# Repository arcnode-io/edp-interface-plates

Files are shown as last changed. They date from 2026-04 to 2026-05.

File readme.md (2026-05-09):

# EDP Interface Plates 🔩📐







> interface plates that mount to container end walls and organize all power, comms, and fluid connections

## Architecture Context

```plantuml
rectangle container_a
rectangle container_b
rectangle plate_a
rectangle plate_b
rectangle flexible_assembly

container_a -r- plate_a: receiver frame (welded)
container_b -l- plate_b: receiver frame (welded)
plate_a -r- flexible_assembly: liquid-tight conduit\nM12 connectors\ncooling QDs
flexible_assembly -r- plate_b
```

Containers are placed face-to-face. Plates mate as a pair via flexible assemblies — there is **no hard-dock interface**. Containers tolerate ±25mm horizontal and ±10mm vertical misalignment, absorbed by hose/cable service loops.

## Power Path

```
External BESS  →  BG  →  Grid Container  →  CG  →  Compute Container (415Y/240V AC)
```

Grid container always present. PCS lives in grid container when BESS is DC-coupled; when AC-coupled the BESS lands on grid switchgear directly.

## Plate Variants

Variant codes follow `[Container A][Container B]-[Coupling]-[String/Port Count]` where applicable.

| Variant | Used When | Carries | Plate Codes |
|---|---|---|---|
| **BG-AC** | External BESS lands AC at grid container (Tesla Megapack, Tesla Megablock, CATL EnerOne with integrated PCS) | AC feeder, grounding, data | `BG-AC` (conduit sized from BESS AC interconnect spec) |
| **BG-DC** | External BESS lands DC at grid container; PCS lives in grid container (CATL EnerOne, external PCS) | DC bus, grounding, data | `BG-DC` (single parametric variant, DC bus OD sized from aggregate string current per ADR-011) |
| **CG** | All deployments | AC feeder (415Y/240V) + data | `CG` (fixed, conduit sized from sizing engine Module F) |
| **CD** | All deployments (1:1 Compute:Drycooler) | Coolant supply/return + drycooler comms (VFD Modbus, fan tach, leak sensor) | `CD` (2" QD class, 200 LPM @ 5 K secondary loop ΔT) |

See the spec doc for full penetration schedules per variant.

## Material & Finish

| Parameter | Standard | Defense (`deployment_context == defense_forward \| sovereign_government`) |
|---|---|---|
| Outer dimensions | 640mm × 840mm | same |
| Thickness | 6mm | 10mm |
| Material | 6061-T6 aluminum (ASTM B209) | 5083-H116 marine grade (ASTM B209) |
| Finish | Type II anodize 15–25 μm (MIL-A-8625) | Type III hard anodize 40–60 μm |
| IP rating | IP55 | IP65 (verified per MIL-STD-810H Method 506) |
| Secondary seal | none | 10mm closed-cell EPDM backer |
| Fasteners | Zn-plated steel M10 (ASTM F593 G1) | 316 SS M10 (ASTM F593 G2) |

## Output Artifacts

For every plate variant required by a deployment, the implementation outputs:

1. **DXF file** — 2D fabrication drawing with plate outline, all hole/cutout locations dimensioned from plate center, gasket groove cross-section, mounting hole pattern with thread callouts, ARCNODE title block (part number, variant code, revision, material spec, finish spec).
2. **BOM line item** — structured JSON referencing the drawing:
   ```json
   {
     "part_number": "ARC-PLT-BG-DC-001",
     "description": "Interface Plate, BESS-to-Grid DC-Coupled, 4-String",
     "qty": 1,
     "material": "6061-T6 aluminum",
     "finish": "Type II anodize",
     "drawing_ref": "ARC-PLT-BG-DC-001.dxf",
     "type": "custom_fabrication"
   }
   ```
3. **Penetration schedule** — table of every hole/cutout: penetration ID, X/Y center coordinates from plate origin, diameter or W×H, fitting spec, OTS part number.

## Part Numbering

```
ARC - PLT - [VARIANT CODE] - [REVISION]

Examples:
  ARC-PLT-BG-AC-001       BESS-Grid, AC-coupled
  ARC-PLT-BG-DC-001       BESS-Grid, DC-coupled (single parametric variant)
  ARC-PLT-CG-001          Compute-Grid
  ARC-PLT-CD-001          Compute-Drycooler

Defense variants append `-D`:
  ARC-PLT-BG-DC-001-D
```

## Toolchain

The fabrication flow is CadQuery-based:

```
parametric model.py (CadQuery) → STEP → DXF + GD&T drawing → BOM line item + penetration schedule
```

```bash
uv sync
uv run poe build              # CadQuery → STEP per variant
uv run poe validate-model     # BRep validity + bbox vs spec
uv run poe generate-drawings  # DXF + GD&T PDF per variant
uv run poe sim                # IP rating verification fixtures
```

## Open Design Parameters

| # | Parameter | Impact |
|---|---|---|
| 1 | GPU vendor DLC loop architecture | CD plate QD port size and count |
| 2 | Dry cooler pipe connection size | CD plate flange size |
| 3 | 4,160V AC option | CG conduit sizing changes significantly at MV |
| 4 | BESS DC string voltage class (1500V vs 800V) | BG-DC isolation distance + bus rating |
| 5 | BESS AC interconnect voltage (480V vs MV) | BG-AC conduit + bushing class |

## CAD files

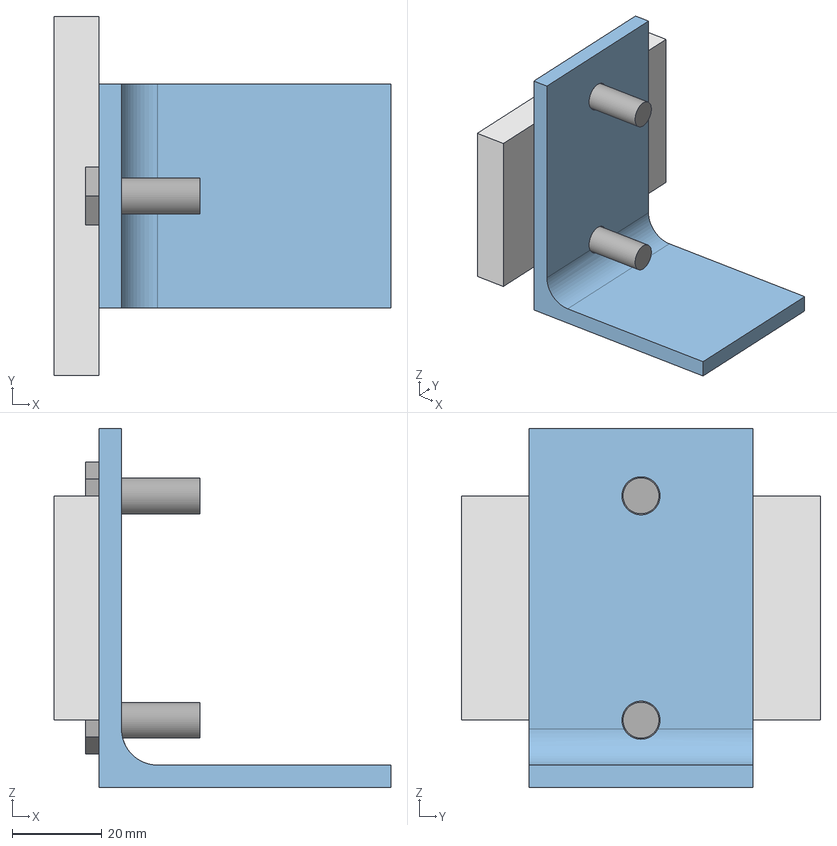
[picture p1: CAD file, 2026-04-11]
output/fab/l_bracket_assy.step
75.0 x 80.0 x 80.0 mm
bracket
wall_plate
bolt_1
bolt_2

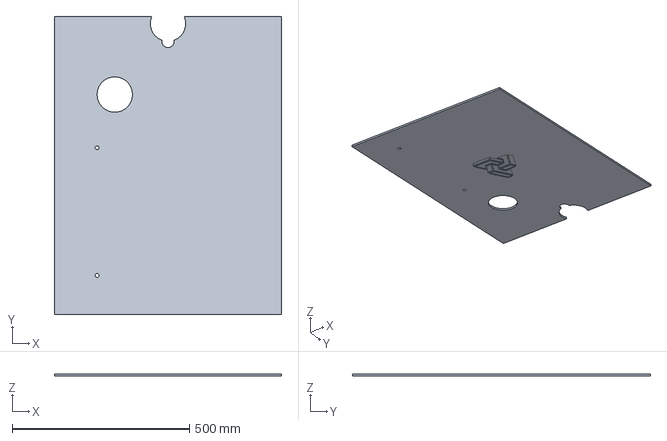
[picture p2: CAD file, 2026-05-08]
cad/BG-AC.step
640.0 x 840.0 x 6.00 mm

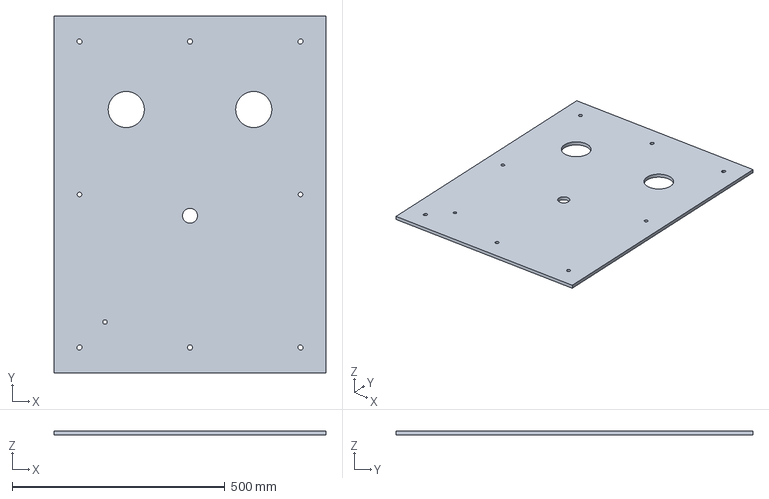
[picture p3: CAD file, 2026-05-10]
cad/specs/BG-DC/plate-defense.step
640.0 x 840.0 x 10.0 mm

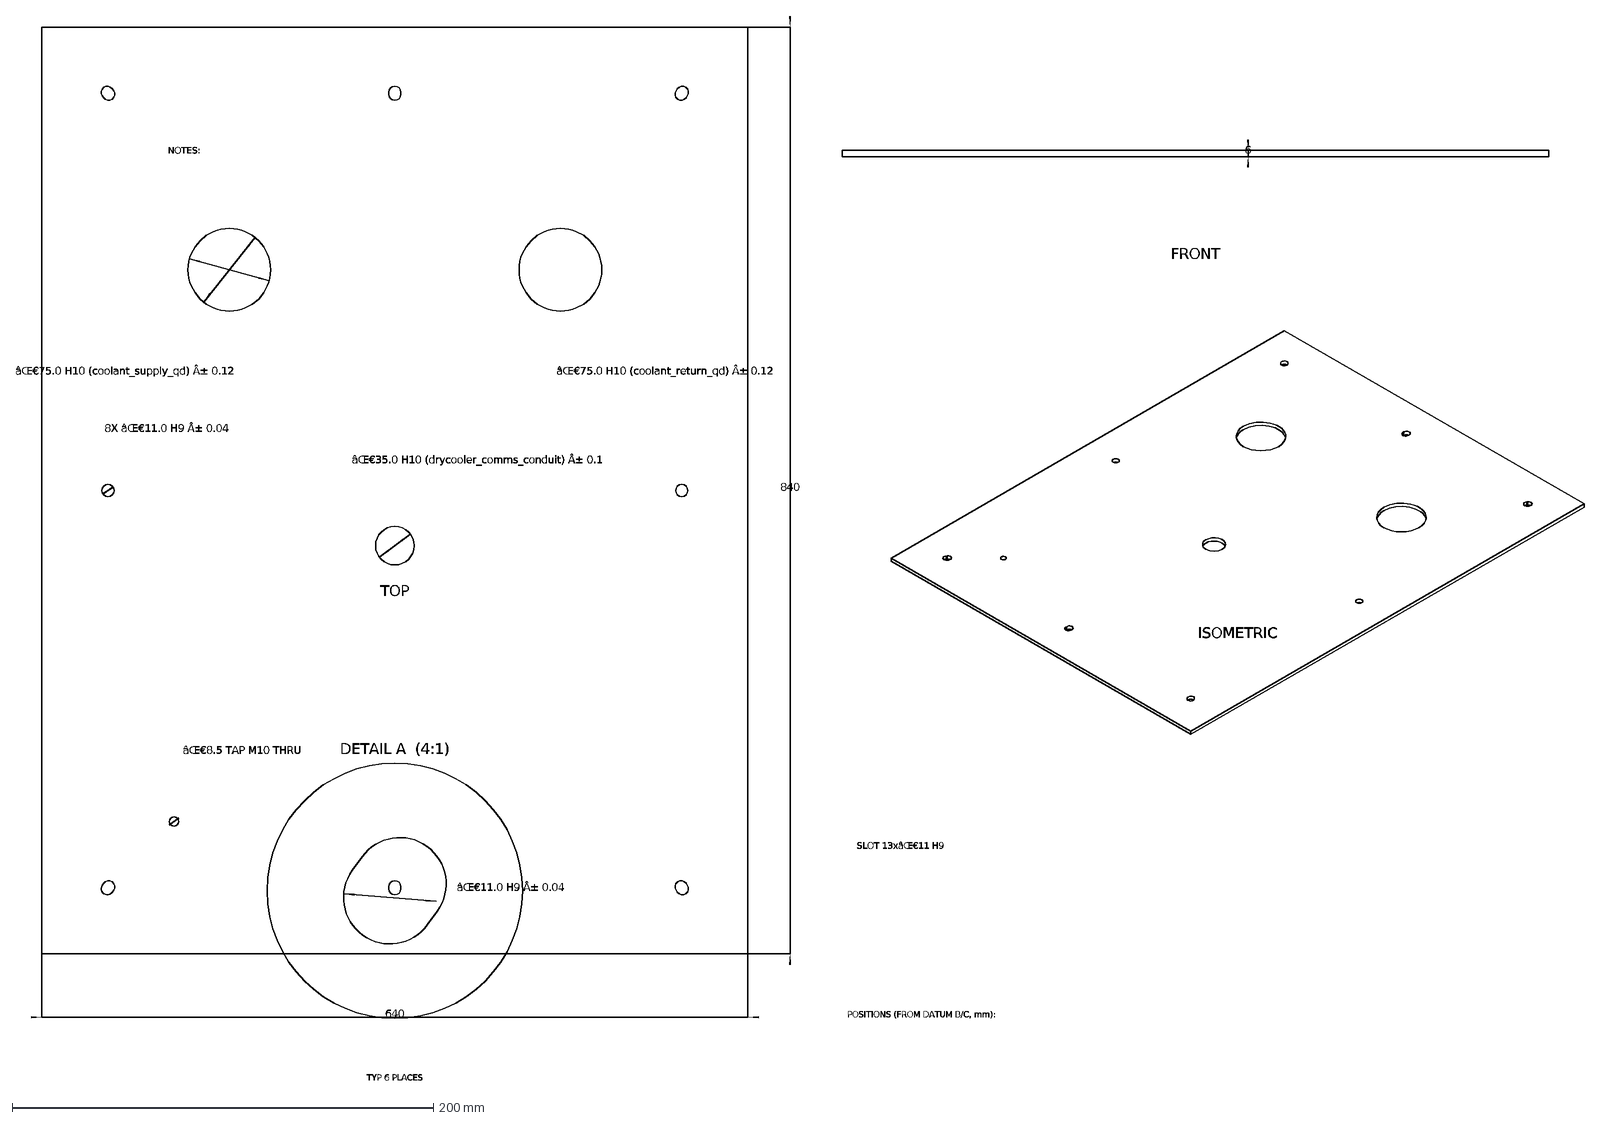
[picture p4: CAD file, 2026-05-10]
output/drawings/CD.dxf
640
840
âŒ€75.0 H10 (coolant_supply_qd) Â± 0.12
âŒ€75.0 H10 (coolant_return_qd) Â± 0.12
âŒ€35.0 H10 (drycooler_comms_conduit) Â± 0.1
âŒ€8.5 TAP M10 THRU
8X âŒ€11.0 H9 Â± 0.04
POSITIONS (FROM DATUM B/C, mm):
SLOT 13xâŒ€11 H9
6
âŒ€11.0 H9 Â± 0.04
TYP 6 PLACES
DETAIL A (4:1)
NOTES:
TOP
FRONT
ISOMETRIC

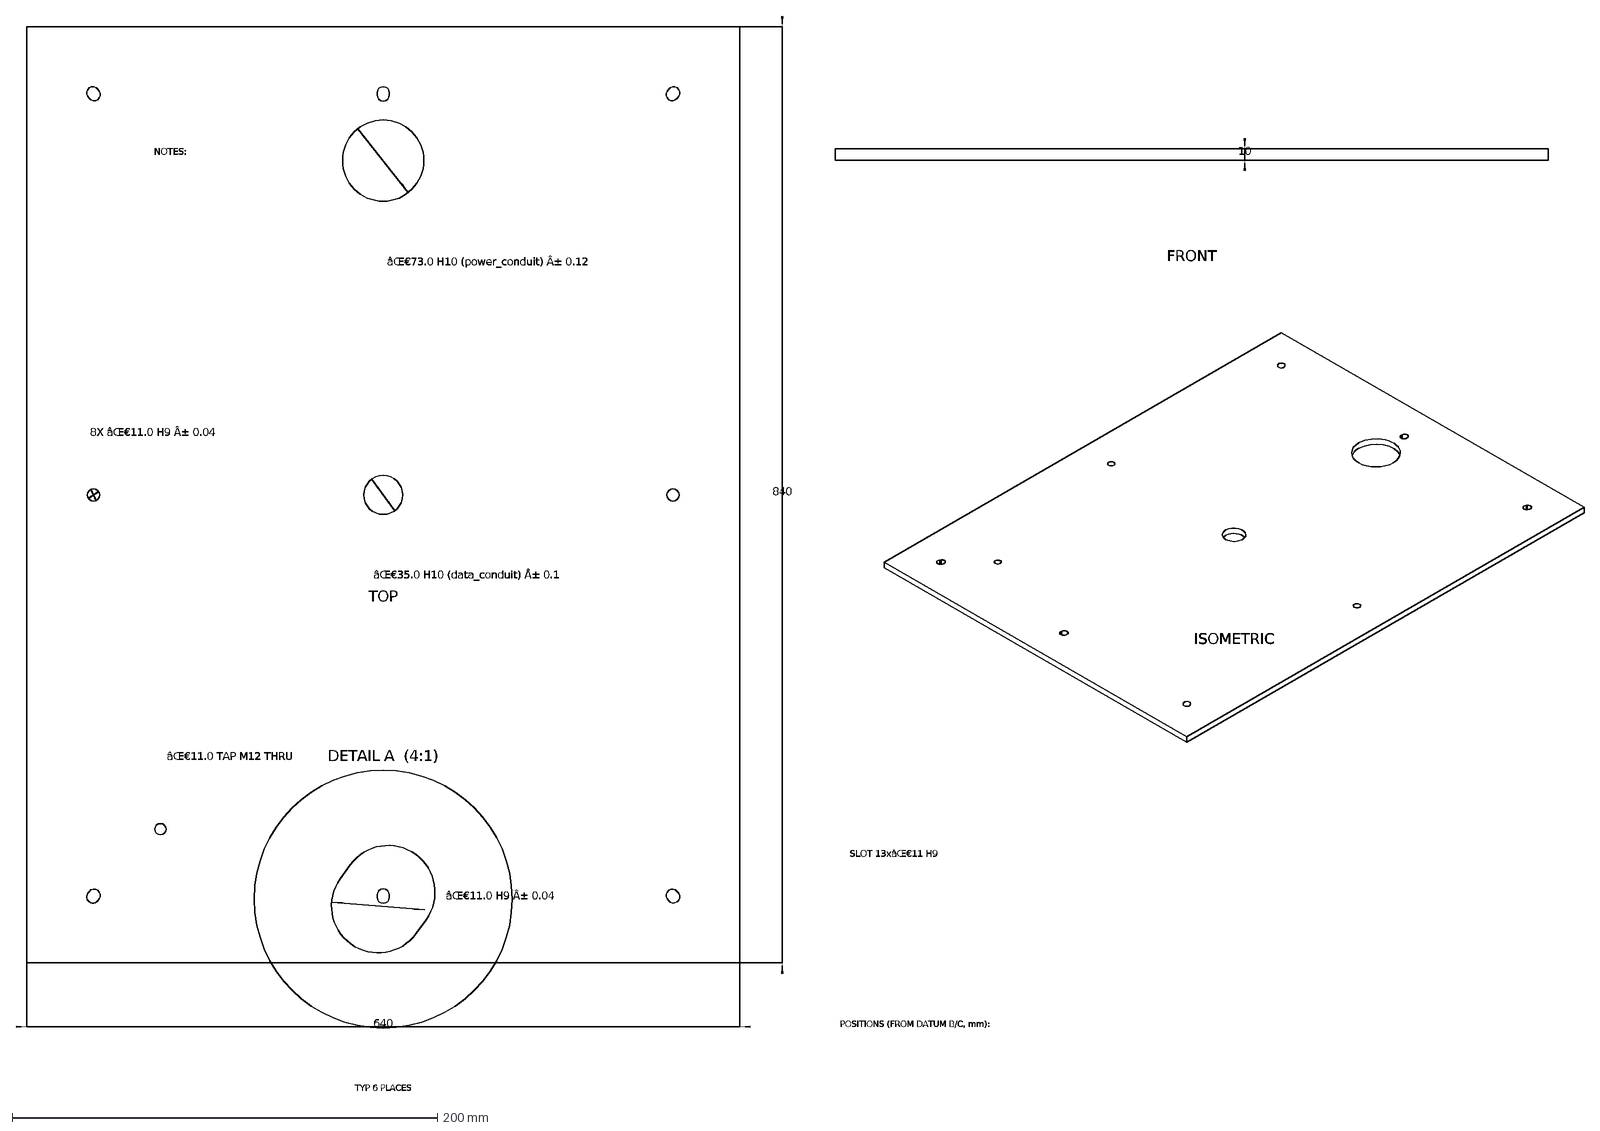
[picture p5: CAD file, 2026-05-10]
output/drawings/CG-defense.dxf
640
840
âŒ€73.0 H10 (power_conduit) Â± 0.12
âŒ€35.0 H10 (data_conduit) Â± 0.1
âŒ€11.0 TAP M12 THRU
8X âŒ€11.0 H9 Â± 0.04
POSITIONS (FROM DATUM B/C, mm):
SLOT 13xâŒ€11 H9
10
âŒ€11.0 H9 Â± 0.04
TYP 6 PLACES
DETAIL A (4:1)
NOTES:
TOP
FRONT
ISOMETRIC

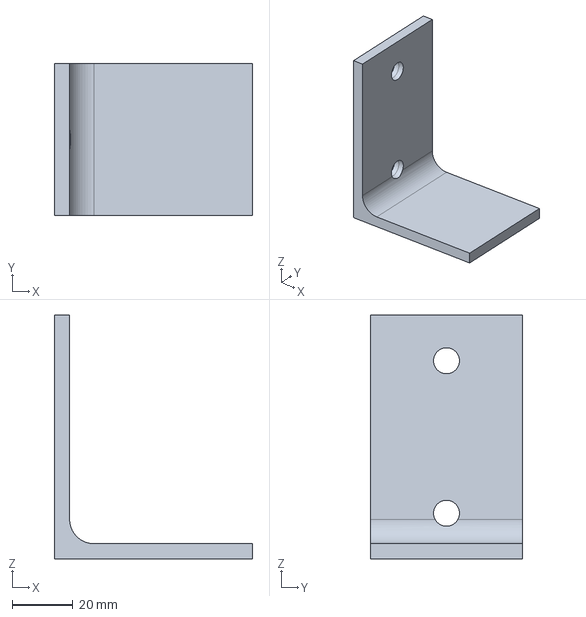
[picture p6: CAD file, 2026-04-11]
output/fab/l_bracket.step
65.0 x 50.0 x 80.0 mm

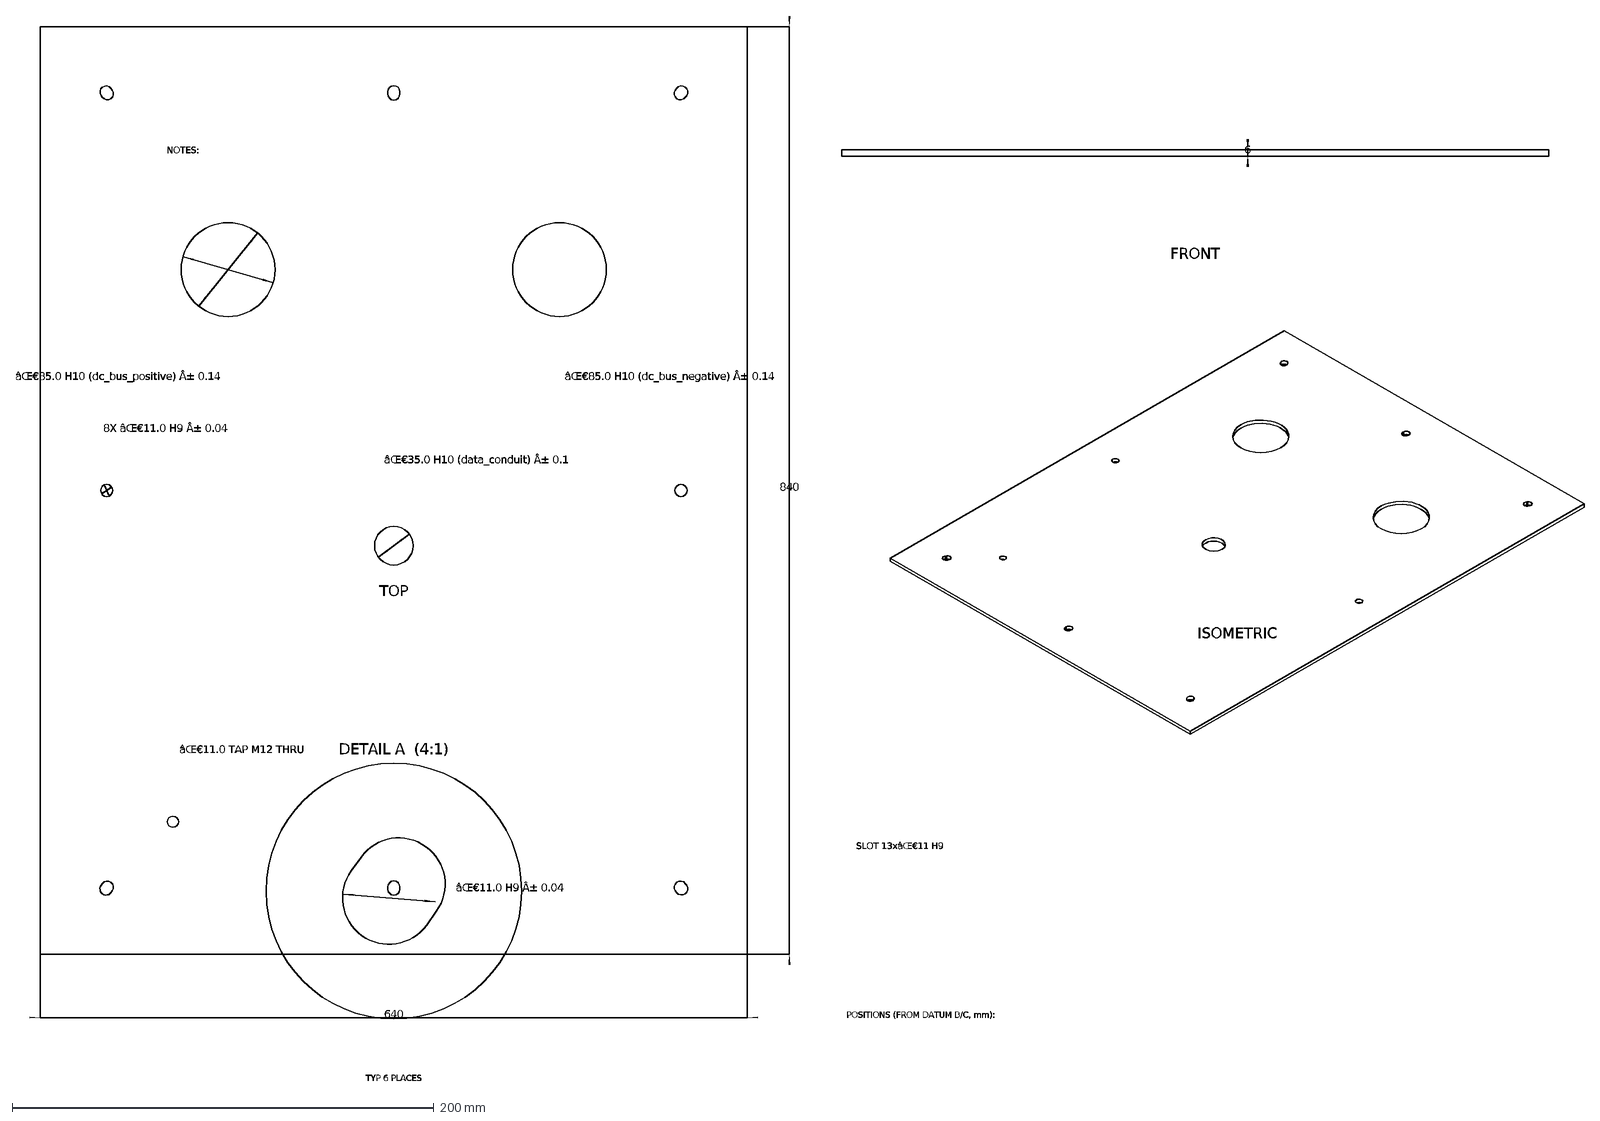
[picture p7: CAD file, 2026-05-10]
output/drawings/BG-DC.dxf
640
840
âŒ€85.0 H10 (dc_bus_positive) Â± 0.14
âŒ€85.0 H10 (dc_bus_negative) Â± 0.14
âŒ€35.0 H10 (data_conduit) Â± 0.1
âŒ€11.0 TAP M12 THRU
8X âŒ€11.0 H9 Â± 0.04
POSITIONS (FROM DATUM B/C, mm):
SLOT 13xâŒ€11 H9
6
âŒ€11.0 H9 Â± 0.04
TYP 6 PLACES
DETAIL A (4:1)
NOTES:
TOP
FRONT
ISOMETRIC

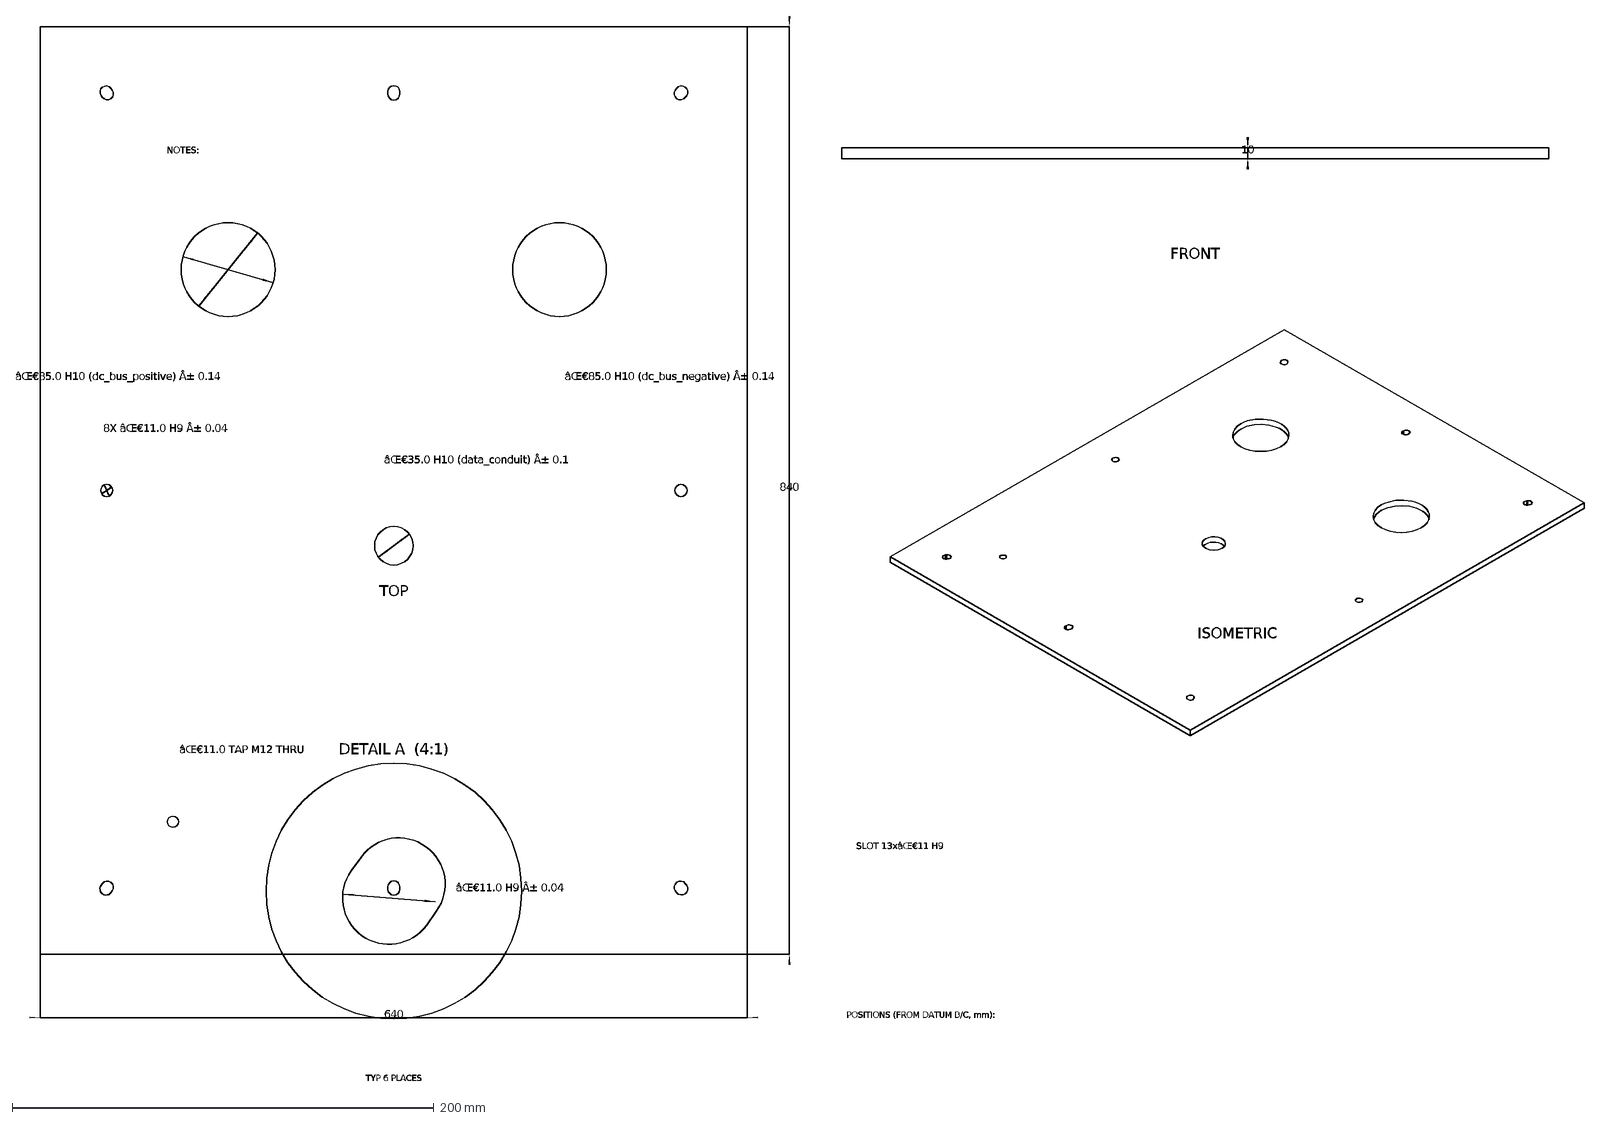
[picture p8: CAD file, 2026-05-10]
output/drawings/BG-DC-defense.dxf
640
840
âŒ€85.0 H10 (dc_bus_positive) Â± 0.14
âŒ€85.0 H10 (dc_bus_negative) Â± 0.14
âŒ€35.0 H10 (data_conduit) Â± 0.1
âŒ€11.0 TAP M12 THRU
8X âŒ€11.0 H9 Â± 0.04
POSITIONS (FROM DATUM B/C, mm):
SLOT 13xâŒ€11 H9
10
âŒ€11.0 H9 Â± 0.04
TYP 6 PLACES
DETAIL A (4:1)
NOTES:
TOP
FRONT
ISOMETRIC

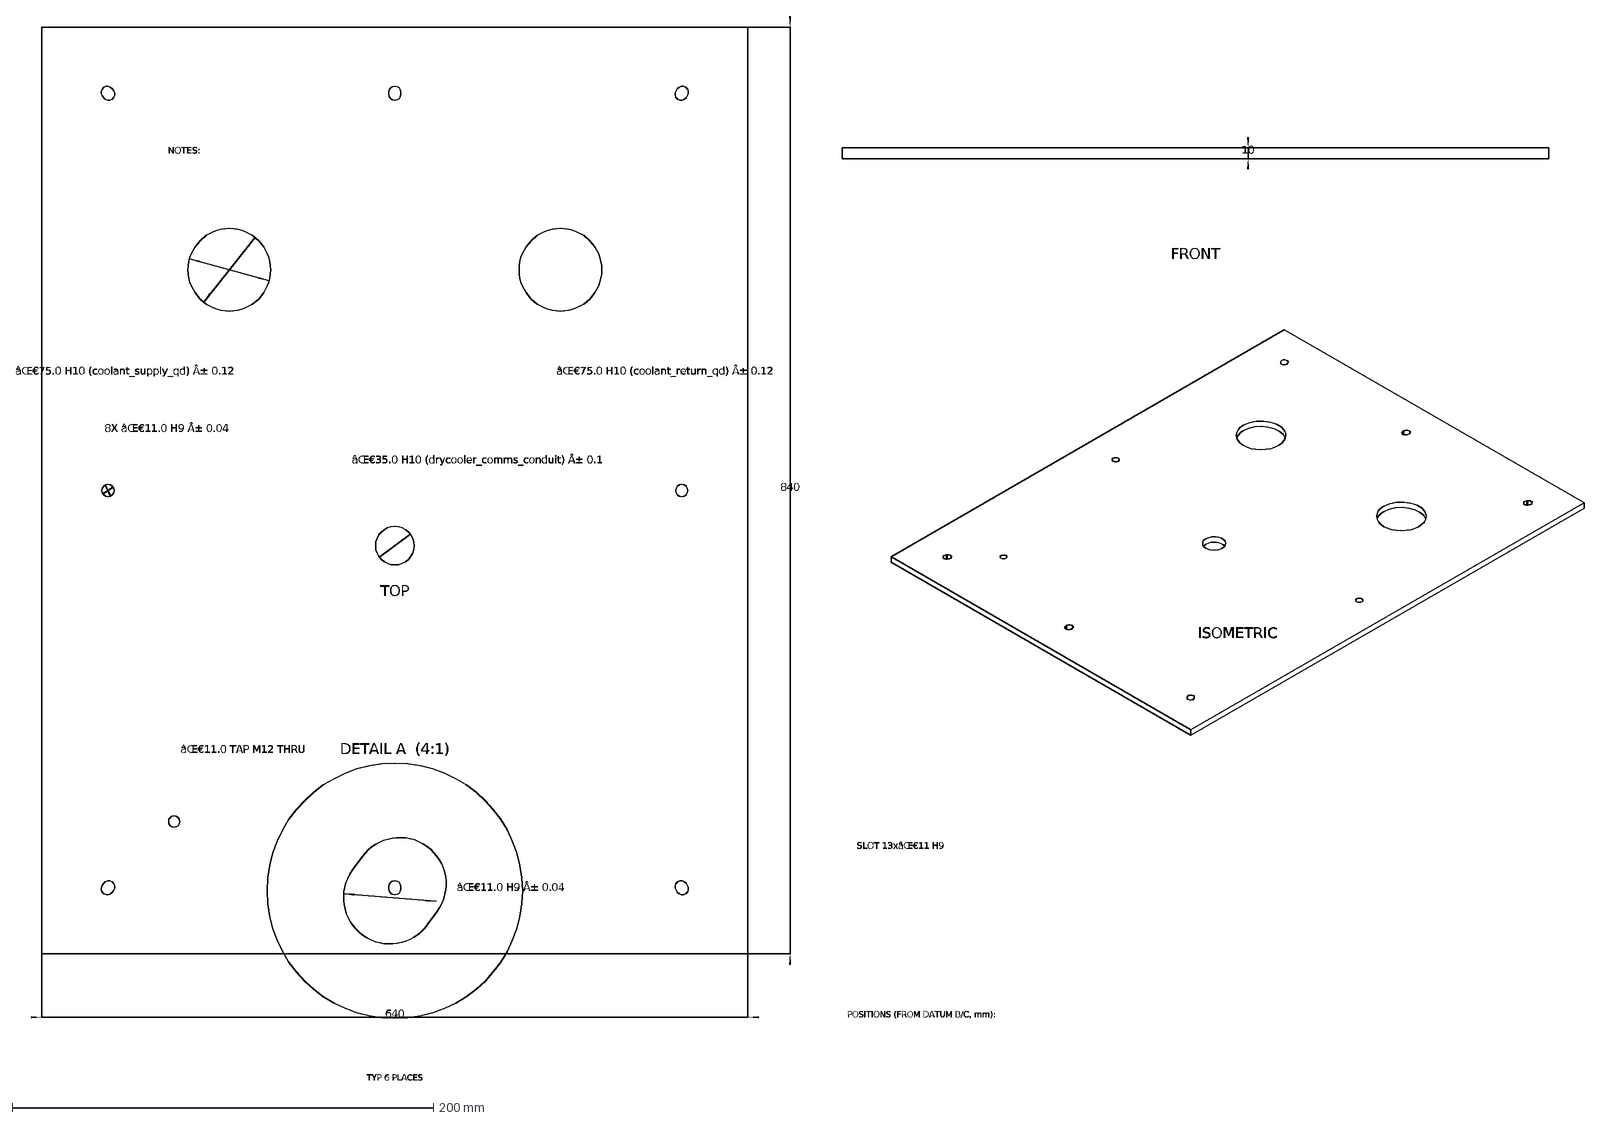
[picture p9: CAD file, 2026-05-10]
output/drawings/CD-defense.dxf
640
840
âŒ€75.0 H10 (coolant_supply_qd) Â± 0.12
âŒ€75.0 H10 (coolant_return_qd) Â± 0.12
âŒ€35.0 H10 (drycooler_comms_conduit) Â± 0.1
âŒ€11.0 TAP M12 THRU
8X âŒ€11.0 H9 Â± 0.04
POSITIONS (FROM DATUM B/C, mm):
SLOT 13xâŒ€11 H9
10
âŒ€11.0 H9 Â± 0.04
TYP 6 PLACES
DETAIL A (4:1)
NOTES:
TOP
FRONT
ISOMETRIC

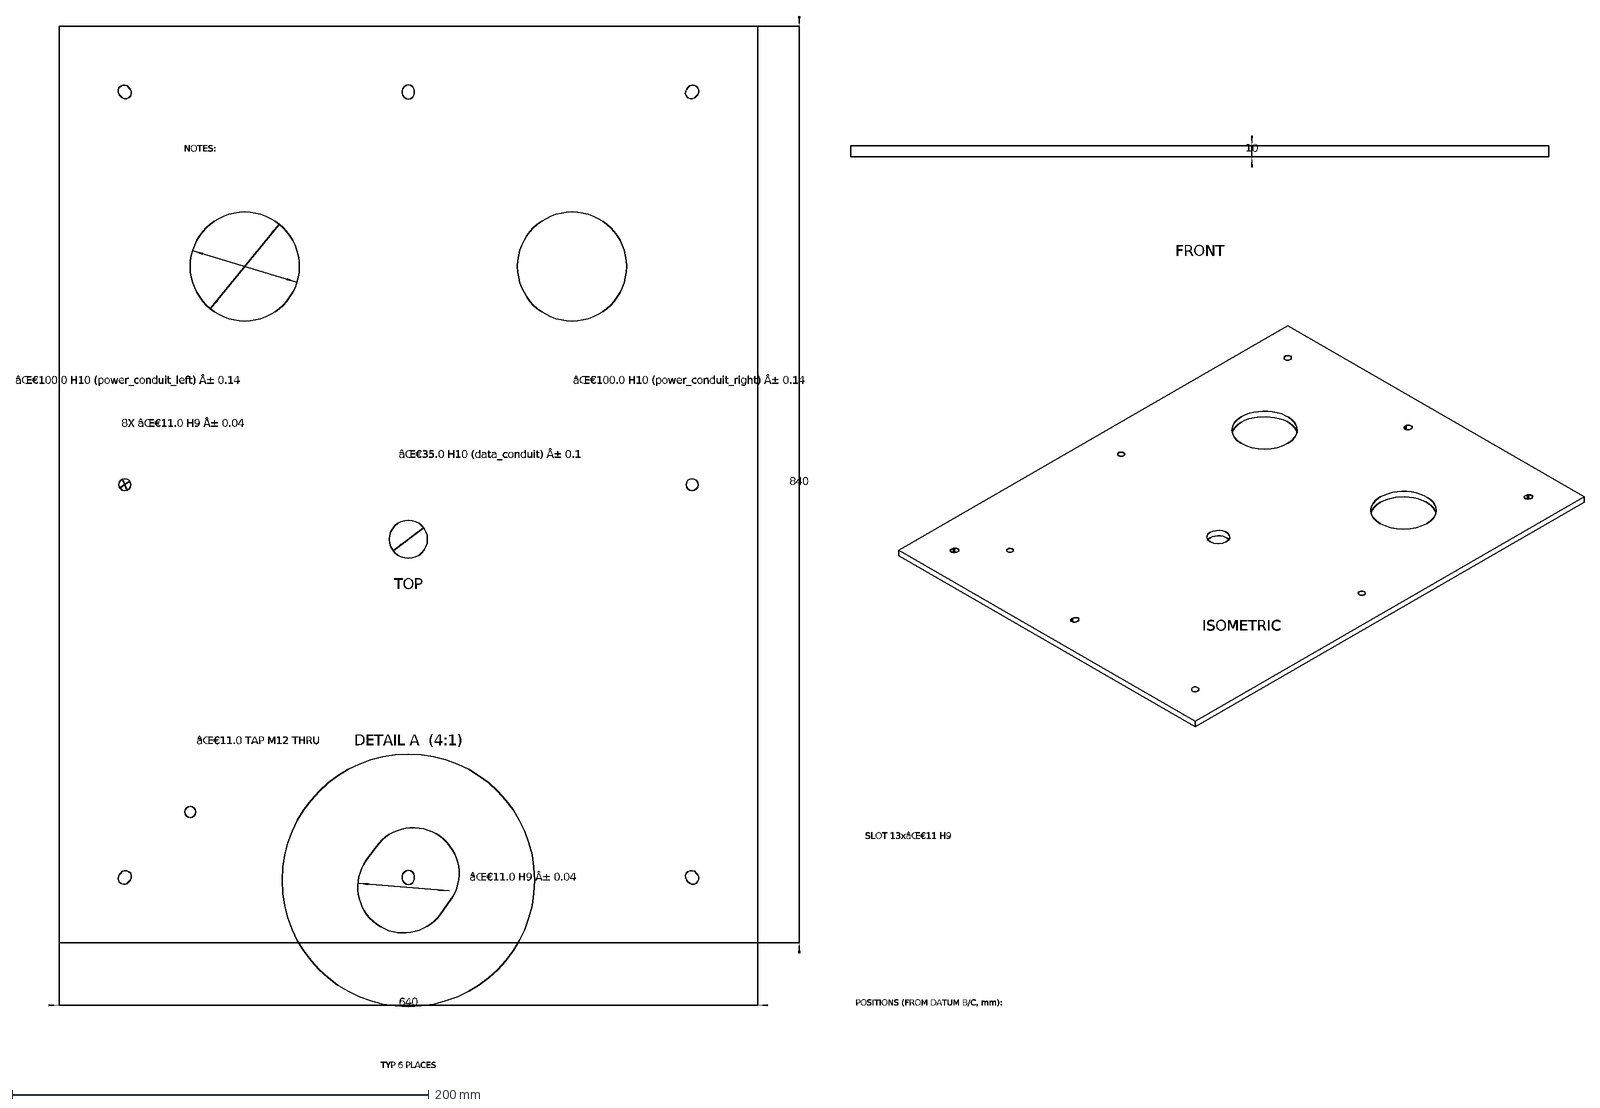
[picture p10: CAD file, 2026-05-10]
output/drawings/BG-AC-defense.dxf
640
840
âŒ€100.0 H10 (power_conduit_left) Â± 0.14
âŒ€100.0 H10 (power_conduit_right) Â± 0.14
âŒ€35.0 H10 (data_conduit) Â± 0.1
âŒ€11.0 TAP M12 THRU
8X âŒ€11.0 H9 Â± 0.04
POSITIONS (FROM DATUM B/C, mm):
SLOT 13xâŒ€11 H9
10
âŒ€11.0 H9 Â± 0.04
TYP 6 PLACES
DETAIL A (4:1)
NOTES:
TOP
FRONT
ISOMETRIC

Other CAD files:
cad/specs/BG-AC/plate.step
cad/specs/CD/plate-defense.step
cad/specs/CG/plate.step
cad/CG.step
cad/specs/BG-AC/plate-defense.step
cad/specs/BG-DC/plate.step
cad/specs/CD/plate.step
cad/specs/CG/plate-defense.step
cad/BG-AC.dxf
cad/CG.dxf
cad/specs/BG-AC/plate-defense.dxf
cad/specs/BG-AC/plate.dxf
cad/specs/BG-DC/plate-defense.dxf
cad/specs/BG-DC/plate.dxf
cad/specs/CD/plate-defense.dxf
cad/specs/CD/plate.dxf
cad/specs/CG/plate-defense.dxf
cad/specs/CG/plate.dxf
cad/specs/EX-C/plate.dxf
cad/specs/EX-G/plate.dxf
output/drawings/BG-AC.dxf
output/drawings/CG.dxf

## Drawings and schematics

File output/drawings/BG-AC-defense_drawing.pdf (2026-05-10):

1

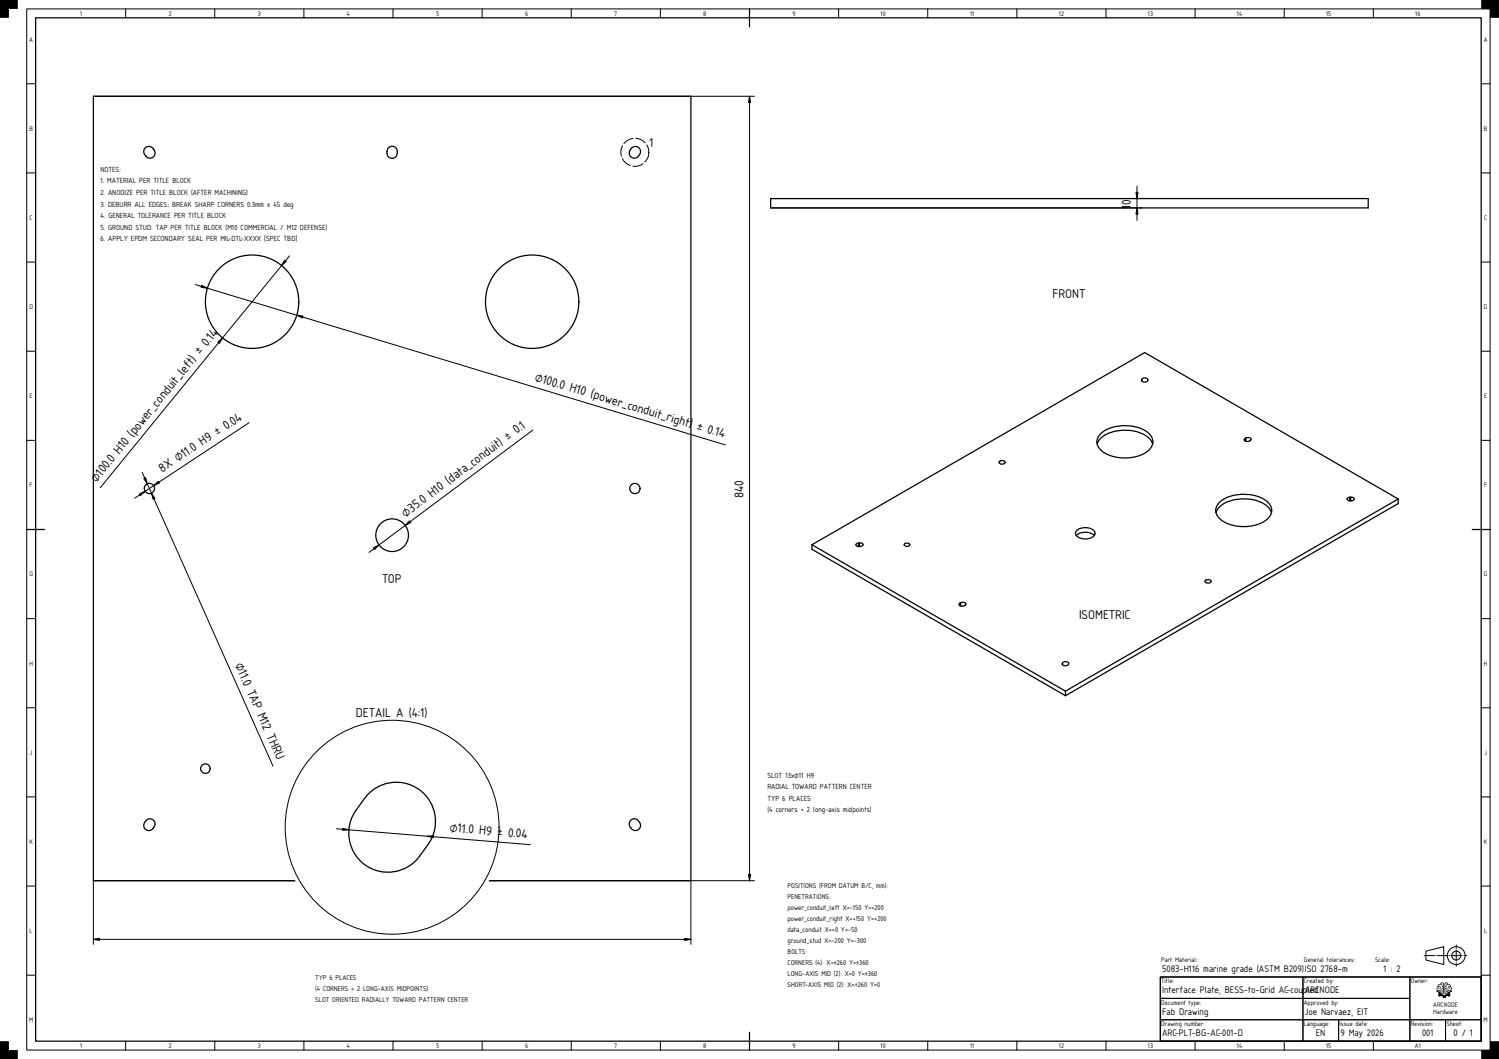
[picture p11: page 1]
Owner:; Drawing number:; Language: Issue date:; Revision:; Sheet:; Part Material:; General tolerances:; Scale:; ARCNODE Hardware; ARC-PLT-BG-AC-001-D; 9 May 2026; 5083-H116 marine grade (ASTM B209)ISO 2768-m; ⌀100.0 H10 (power_conduit_left) ± 0.14; ⌀100.0 H10 (power_conduit_right) ± 0.14; ⌀35.0 H10 (data_conduit) ± 0.1; ⌀11.0 TAP M12 THRU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

NOTES:
1. MATERIAL PER TITLE BLOCK
2. ANODIZE PER TITLE BLOCK (AFTER MACHINING)
3. DEBURR ALL EDGES; BREAK SHARP CORNERS 0.3mm x 45 deg
4. GENERAL TOLERANCE PER TITLE BLOCK
5. GROUND STUD: TAP PER TITLE BLOCK (M10 COMMERCIAL / M12 DEFENSE)
6. APPLY EPDM SECONDARY SEAL PER MIL-DTL-XXXX [SPEC TBD]

SLOT 13x⌀11 H9
RADIAL TOWARD PATTERN CENTER
TYP 6 PLACES
(4 corners + 2 long-axis midpoints)

Title:
Interface Plate, BESS-to-Grid AC-coupled
Document type:
Fab Drawing

(4 CORNERS + 2 LONG-AXIS MIDPOINTS)
SLOT ORIENTED RADIALLY TOWARD PATTERN CENTER

Created by:
ARCNODE
Approved by:
Joe Narvaez, EIT

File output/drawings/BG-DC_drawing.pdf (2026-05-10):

1

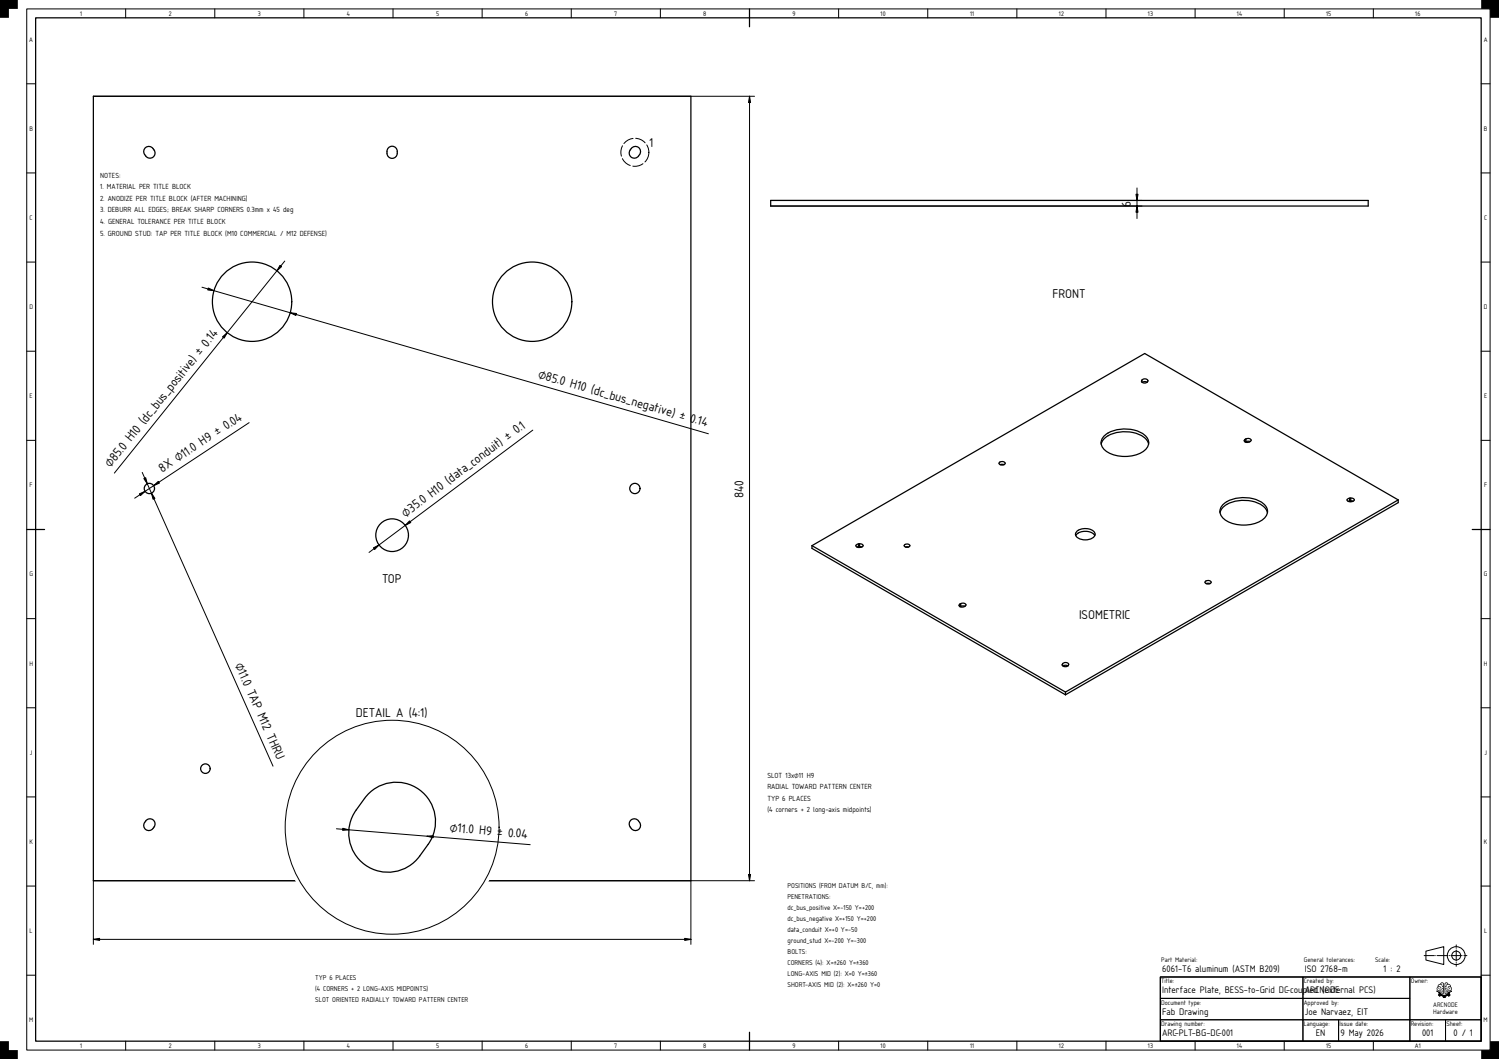
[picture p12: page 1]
Owner:; Drawing number:; Language: Issue date:; Revision:; Sheet:; Part Material:; General tolerances:; Scale:; ARCNODE Hardware; ARC-PLT-BG-DC-001; 9 May 2026; 6061-T6 aluminum (ASTM B209); ISO 2768-m; ⌀85.0 H10 (dc_bus_positive) ± 0.14; ⌀85.0 H10 (dc_bus_negative) ± 0.14; ⌀35.0 H10 (data_conduit) ± 0.1; ⌀11.0 TAP M12 THRU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

Title:
Interface Plate, BESS-to-Grid DC-coupled (external PCS)
Document type:
Fab Drawing

(4 CORNERS + 2 LONG-AXIS MIDPOINTS)
SLOT ORIENTED RADIALLY TOWARD PATTERN CENTER

Created by:
ARCNODE
Approved by:
Joe Narvaez, EIT

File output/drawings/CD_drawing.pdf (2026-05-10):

1

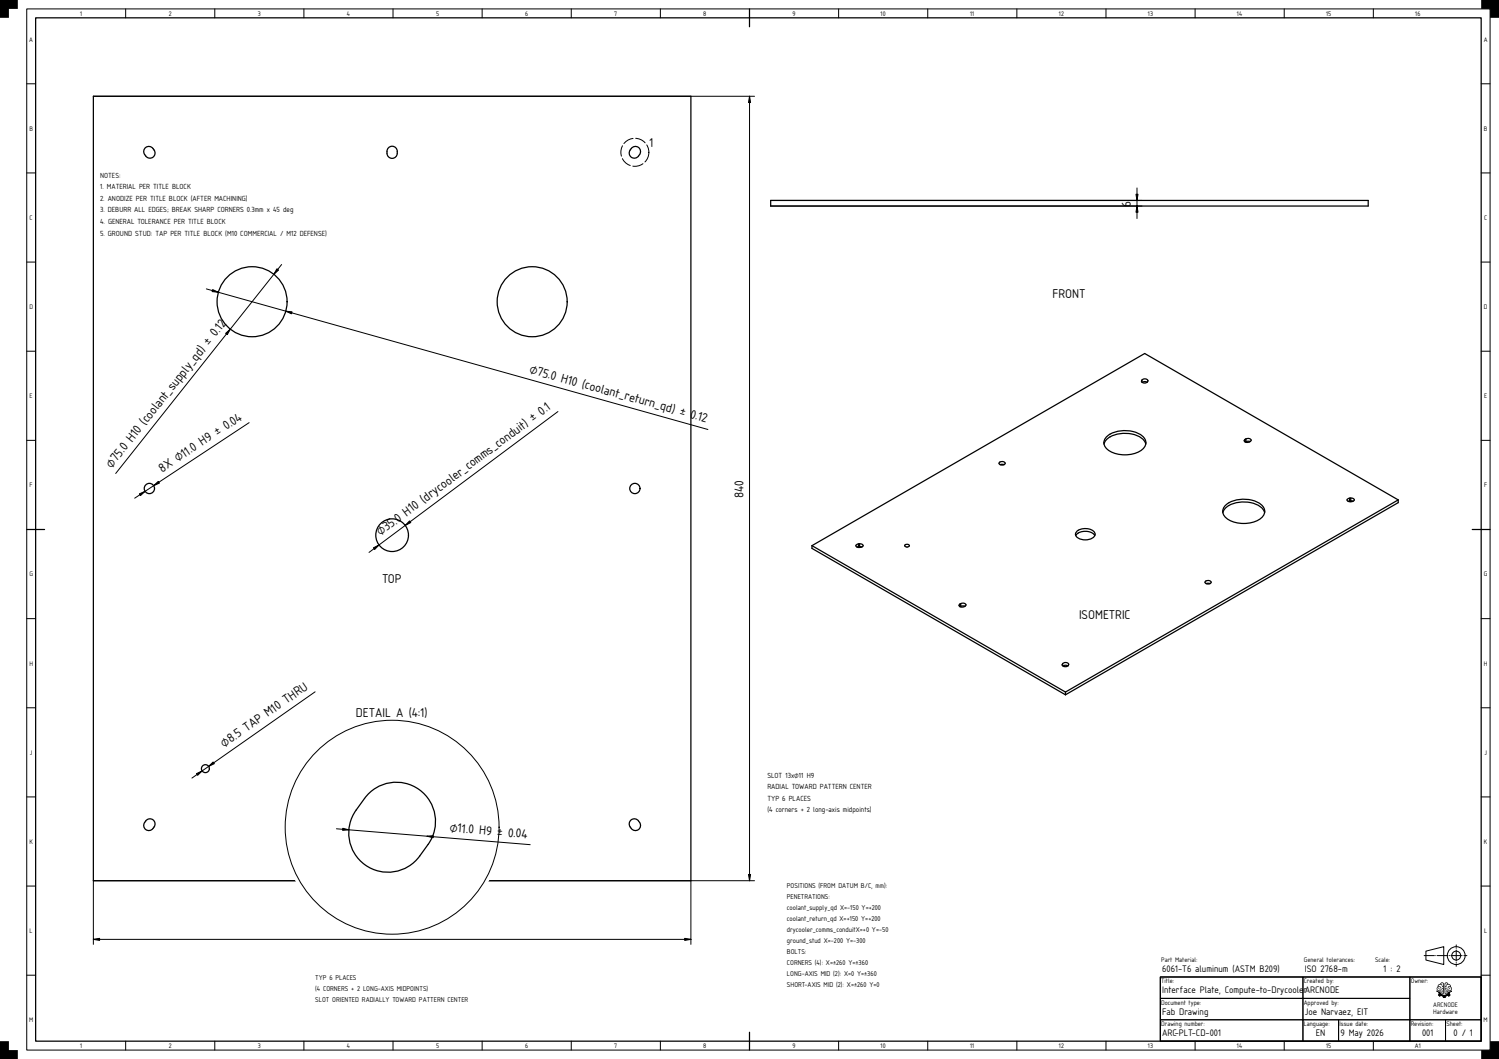
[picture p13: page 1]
Owner:; Drawing number:; Language: Issue date:; Revision:; Sheet:; Part Material:; General tolerances:; Scale:; ARCNODE Hardware; ARC-PLT-CD-001; 9 May 2026; 6061-T6 aluminum (ASTM B209); ISO 2768-m; ⌀75.0 H10 (coolant_supply_qd) ± 0.12; ⌀75.0 H10 (coolant_return_qd) ± 0.12; ⌀35.0 H10 (drycooler_comms_conduit) ± 0.1; ⌀8.5 TAP M10 THRU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

Title:
Interface Plate, Compute-to-Drycooler
Document type:
Fab Drawing

(4 CORNERS + 2 LONG-AXIS MIDPOINTS)
SLOT ORIENTED RADIALLY TOWARD PATTERN CENTER

Created by:
ARCNODE
Approved by:
Joe Narvaez, EIT

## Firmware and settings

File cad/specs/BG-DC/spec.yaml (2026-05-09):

plate_id: BG-DC
schema_version: "0"
description: "Interface Plate, BESS-to-Grid DC-coupled (external PCS)"

# BG-DC mounts on grid container's BESS-facing end wall (+X side per ADR-007
# convention; mirror of CG plate which is on the compute-facing -X end).
# Used for commercial_dc_ext profile: PCS lives INSIDE grid container, BESS
# pad outputs DC strings directly. BG-DC carries DC bus from BESS to grid
# container's PCS input (e.g. CATL EnerOne with external PCS, NHOA Atlante
# DC-string deployments).
mating_pair:
  side_a: bess_dc_string
  side_b: grid_container

outer_dims_mm:
  L: 840   # vertical extent on container end wall (matches BG-AC)
  W: 640   # horizontal extent (matches BG-AC)

# Same deployment_contexts framework as BG-AC. Material/finish/IP toggle
# as a SET; only ground stud size and ampacity-driven cutout sizes differ.
deployment_contexts:
  commercial:
    material: "6061-T6 aluminum (ASTM B209)"
    finish: "Type II anodize 15-25 μm (MIL-A-8625)"
    thickness_mm: 6
    ip_rating: IP55
    fasteners: "Zn-plated steel M10 (ASTM F593 G1)"
    secondary_seal: null
    ground_stud: M12   # Reason: DC fault is sustained — M12 minimum
  defense_forward:
    material: "5083-H116 marine grade (ASTM B209)"
    finish: "Type III hard anodize 40-60 μm"
    thickness_mm: 10
    ip_rating: IP65
    fasteners: "316 SS M10 (ASTM F593 G2)"
    secondary_seal: "10mm closed-cell EPDM backer"
    ground_stud: M12
  sovereign_government:
    material: "5083-H116 marine grade (ASTM B209)"
    finish: "Type III hard anodize 40-60 μm"
    thickness_mm: 10
    ip_rating: IP65
    fasteners: "316 SS M10 (ASTM F593 G2)"
    secondary_seal: "10mm closed-cell EPDM backer"
    ground_stud: M12

# Penetration schedule: DC+ bus + DC- bus + 1x data + 1x ground stud.
# Same position geometry as BG-AC (2 power + data + ground) so the same
# receiver-frame welding fixture works across BG-* plate variants.
# Cutout DIAMETERS driven by build-time params (sizing engine output).
penetration_schedule:
  - id: dc_bus_positive
    x_mm: -150
    y_mm: 200
    size_driver: param.power_conduit_od_mm
    fitting_spec: DC bus duct hub, threaded with isolation bushing
    ots_pn: TBD_after_DC_busway_supplier_selection
    notes: |
      DC+ bus from BESS string array. v1 commercial sized for 4-string
      aggregate at 1 MW / 1500V = ~667A → 3" DC bus duct hub OD ~85mm.
      Real sizing comes from edp-api Module F per ADR-011, taking actual
      BESS string voltage class (800V or 1500V) as input. Isolation
      bushing required per IEC 61439-6 §11.6 (live-part separation).
  - id: dc_bus_negative
    x_mm: 150
    y_mm: 200
    size_driver: param.power_conduit_od_mm
    fitting_spec: DC bus duct hub, threaded with isolation bushing
    ots_pn: TBD_after_DC_busway_supplier_selection
    notes: |
      DC- bus, paired with positive bus at min 300mm spacing for
      arc-flash isolation per NFPA 70E Table 130.7(C)(15)(a). v1 commercial
      uses 300mm separation (positions ±150mm from center).
  - id: data_conduit
    x_mm: 0
    y_mm: -50
    size_driver: param.data_conduit_od_mm
    fitting_spec: EMT conduit hub, threaded
    ots_pn: TBD_after_conduit_supplier_selection
    notes: |
      BESS BMS comms (Modbus TCP, CAN, or DNP3 per BESS vendor). v1 sized
      for fiber + copper bundle in 1¼" EMT → ~35mm OD.
  - id: ground_stud
    x_mm: -200
    y_mm: -300
    size_driver: context.ground_stud
    fitting_spec: tapped, sealed with conductive gasket
    ots_pn: N/A (machined into plate)
    notes: |
      M12 ground stud — DC fault is sustained until contactor opens
      (no zero crossing), so ground bonding must handle higher I²t.
      Located near plate corner for access to grounding bus.

# v1 commercial build params (sizing engine Module F output).
# 4-string aggregate at 1 MW / 1500V DC = 667A → 3" DC bus duct hub OD ~85mm.
# Future BG-DC-2 (2-string) and BG-DC-8 (8-string) variants override this.
default_params:
  power_conduit_od_mm: 85.0
  data_conduit_od_mm: 35.0
  data_conduit_count: 1
  deployment_context: commercial
  revision: "001"

# Same 8-bolt perimeter pattern as BG-AC — receiver frame on grid container
# +X end wall is identical across BG-* plate variants for fab simplicity.
# Corners + long-axis midpoints slotted radially per Option 1 thermal
# mitigation (see CG spec / theory.ipynb).
mounting_bolts:
  count: 8
  inset_mm: 60
  diameter_mm: 11
  pattern: corners_and_edge_midpoints
  slot_length_mm: 13
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

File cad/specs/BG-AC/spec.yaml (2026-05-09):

plate_id: BG-AC
schema_version: "0"
description: "Interface Plate, BESS-to-Grid AC-coupled"

# BG-AC mounts on grid container's BESS-facing end wall (-X side per ADR-007
# convention; mirror of CG plate which is on the compute-facing end). Connects
# external customer BESS pad cable trench to grid container internal AC bus
# via switchgear. Used when BESS lands AC at grid (Tesla Megapack, Megablock,
# CATL EnerOne with integrated PCS).
mating_pair:
  side_a: bess_pad
  side_b: grid_container

outer_dims_mm:
  L: 840   # vertical extent on container end wall (matches CG)
  W: 640   # horizontal extent (matches CG)

# Shared deployment_contexts table — toggle as a SET. Identical material/
# fastener/finish to CG; only varies if BESS-specific seal requirements
# emerge (none known v1).
deployment_contexts:
  commercial:
    material: "6061-T6 aluminum (ASTM B209)"
    finish: "Type II anodize 15-25 μm (MIL-A-8625)"
    thickness_mm: 6
    ip_rating: IP55
    fasteners: "Zn-plated steel M10 (ASTM F593 G1)"
    secondary_seal: null
    ground_stud: M12   # Reason: BESS fault current >> compute load; M12 minimum
  defense_forward:
    material: "5083-H116 marine grade (ASTM B209)"
    finish: "Type III hard anodize 40-60 μm"
    thickness_mm: 10
    ip_rating: IP65
    fasteners: "316 SS M10 (ASTM F593 G2)"
    secondary_seal: "10mm closed-cell EPDM backer"
    ground_stud: M12
  sovereign_government:
    material: "5083-H116 marine grade (ASTM B209)"
    finish: "Type III hard anodize 40-60 μm"
    thickness_mm: 10
    ip_rating: IP65
    fasteners: "316 SS M10 (ASTM F593 G2)"
    secondary_seal: "10mm closed-cell EPDM backer"
    ground_stud: M12

# Penetration positions are constants of the BG-AC variant design.
# 2x parallel AC feeders (BESS interconnects via paired conductors at
# megawatt scale), 1x data conduit, 1x ground stud.
# Cutout DIAMETERS driven by build-time params (sizing engine output).
penetration_schedule:
  - id: power_conduit_left
    x_mm: -150
    y_mm: 200
    size_driver: param.power_conduit_od_mm
    fitting_spec: rigid steel conduit hub, threaded
    ots_pn: TBD_after_conduit_supplier_selection
    notes: |
      Left AC feeder. v1 commercial sized for Tesla Megapack 1MW @ 480V
      = ~1200A peak, split between two parallel conductors -> 600A each
      -> ~3.5" rigid conduit hub OD ~100mm.
  - id: power_conduit_right
    x_mm: 150
    y_mm: 200
    size_driver: param.power_conduit_od_mm
    fitting_spec: rigid steel conduit hub, threaded
    ots_pn: TBD_after_conduit_supplier_selection
    notes: Right AC feeder, parallel to left for redundancy + ampacity split.
  - id: data_conduit
    x_mm: 0
    y_mm: -50
    size_driver: param.data_conduit_od_mm
    fitting_spec: EMT conduit hub, threaded
    ots_pn: TBD_after_conduit_supplier_selection
    notes: |
      BESS BMS comms (Modbus TCP per Tesla Powerhub or DNP3 per CATL).
      v1 sized for fiber + copper bundle in 1¼" EMT -> ~35mm OD.
  - id: ground_stud
    x_mm: -200
    y_mm: -300
    size_driver: context.ground_stud
    fitting_spec: tapped, sealed with conductive gasket
    ots_pn: N/A (machined into plate)
    notes: |
      M12 ground stud (vs CG's M10) — sized for BESS fault current path.
      Located near plate corner for access to grounding bus along
      container floor.

# v1 commercial build params (sizing engine Module F output).
# Tesla Megapack 2 XL: 1 MW @ 480V = 1200A peak, split across 2 parallel
# feeders @ 600A each → ~3.5" rigid conduit hub OD ~100mm.
default_params:
  power_conduit_od_mm: 100.0
  data_conduit_od_mm: 35.0
  data_conduit_count: 1
  deployment_context: commercial
  revision: "001"

# Same 8-bolt perimeter pattern as CG — receiver frame on container end
# wall is identical across plate variants for fab simplicity. Corners +
# long-axis midpoints slotted radially per Option 1 thermal mitigation
# (see CG spec / theory.ipynb).
mounting_bolts:
  count: 8
  inset_mm: 60
  diameter_mm: 11   # M10 clearance hole
  pattern: corners_and_edge_midpoints
  slot_length_mm: 13

provenance:
  authored_by: human
  authored_date: 2026-05-07
  reviewed_by: Joe Narvaez, EIT
  reviewed_date: 2026-05-09
  confidence_flags:
    - field: penetration_schedule[*].ots_pn
      flag: missing
      note: Conduit hub vendor selection pending procurement engagement.
    - field: penetration_schedule.power_conduit_*.size_driver
      flag: assumed_default
      note: |
        v1 sizing assumes Tesla Megapack 2 XL: 1MW / 480V / 1200A peak,
        2 parallel feeders @ 600A each. Real sizing comes from edp-api
        Module F per ADR-011, taking actual BESS spec as input. v1
        commercial value: power_conduit_od_mm = 100.
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

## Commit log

2026-04-11 feat: scaffold from template
    [interface_plate.step, interface_plate_assy.step, l_bracket.dxf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]
2026-04-12 🏷️ fix: rename pyproject/package names to arcnode project names
2026-04-12 📝 fix: remove template repo reference from public readme
2026-05-01 🐛 fix: init right_half_cx + narrow solid type in validate
2026-05-01 🔧 build: regenerate l_bracket.step
    [l_bracket.step]
2026-05-02 ♻️ refactor: collapse plate matrix to BG-AC/BG-DC/CG/CD/EX-{G,C}
    BG splits into AC and DC variants per BESS coupling. CD added for
    compute↔drycooler. CG/EX-G/EX-C retained.
2026-05-07 ✨ feat: parametric CG plate (model + drawing + spec)
    Per ADR-008 + Q4/Q15: CG plate cadquery model parametric on conduit OD
    + deployment_context, reads cad/specs/CG/spec.yaml for design constants.
    Drawing pipeline emits DXF + JSON metadata sidecar (full GD&T deferred).
    [CG.dxf, CG.step]
2026-05-07 ✨ feat: ARCNODE logo engraving on plate face (reusable)
    New cad/model/engraving.py — SVG path → CadQuery sketch → cut from plate.
    Even-odd fill handles nested subpaths as holes naturally; outward_normal_z
    selects the engraved face and mirrors x so the logo reads correctly from
    outside. Applied to CG plate; reusable for future plate types.
    [CG.step]
2026-05-07 ✨ feat: BG-AC plate (step 6.2) + extract _plate/_drawing modules
    Step 6.2 per Q16: BESS-to-Grid AC-coupled plate. Lands at grid
    container +X end wall (BESS-facing); mirror of CG plate at -X.
    BG-AC design:
    - 2x parallel AC feeders sized for Tesla Megapack 2 XL: 1MW @ 480V
    -> 1200A peak, 600A per feeder, ~3.5" rigid conduit (100mm OD)
    - 1x data conduit (Modbus TCP per Powerhub or DNP3 per CATL)
    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
    [BG-AC.dxf, BG-AC.step, CG.step]
2026-05-08 🚧 feat: plate GD&T drawing pipeline (v1, layout WIP)
    Per generate-gdt skill: parametric plate variants now have a FreeCAD
    TechDraw-based drawing pipeline that emits A3 PDF + DXF with:
    - Title block populated from plate spec.yaml + drawing_meta
    (part_number ARC-PLT-{id}-{rev}, material, finish, ISO 2768-m
    general tolerance, scale)
    - Face-view dimensions auto-placed by edge-matching:
    * outer width + height
    * penetration diameters (resolved via spec.yaml size_drivers
    against build params)
    * bolt-circle diameter (8x H9 callout)
    - Multi-view layout (TOP face, FRONT edge, ISOMETRIC)
    New modules:
    - cad/drawing/export_plate_drawing.py — CLI entry per plate-id
    - cad/drawing/plate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
    [BG-AC.dxf, CG.dxf]
2026-05-08 🔥 chore: drop L-bracket reference + cantilever sim — plates only
    Repo is for interface plates; L-bracket scaffolding from initial
    cadquery+FEA bootstrap has served its purpose. Patterns are codified
    in cad/model/_plate.py + cad/drawing/_drawing.py + the CLAUDE.md
    reference docs (cadquery + gmsh + pygccx + theory notebook structure).
    Removed:
    - cad/l_bracket.step, cad/interface_plate*.step (legacy stubs)
    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
    [BG-AC.step, CG.step, interface_plate.step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]
2026-05-08 ✨ feat: theory notebook + per-plate sim (template-shaped)
    Per CLAUDE.md TDD pattern: theory.ipynb derives expected values, sim/
    asserts via FEM/analytical model. For these load cases (fault joint
    heating + thermal expansion differential) both have closed-form
    analytical solutions exact under linear-elastic + lumped-thermal
    assumptions, so model.py is analytical (no FEM call needed).
    Two load cases per plate (per user direction):
    1. Bolt pattern under fault current — joint temp rise ≤ 150°C threshold
    2. Thermal expansion differential — corner-bolt offset ≤ bolt clearance
    Layout follows EWAI mechanical-model template structure:
    sim/{plate_id}/
    constants.py # pint units + u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
2026-05-08 🔥 chore: colocate plate artifacts under cad/specs/{plate_id}/
    cad/ top level had a mixed bag of plate outputs (CG.step, BG-AC.step,
    *.dxf, *_drawing_meta.json) alongside source dirs (drawing/, model/).
    Moved all per-plate artifacts into per-plate dirs:
    cad/specs/CG/{spec.yaml, plate.step, plate.dxf, drawing_meta.json}
    cad/specs/BG-AC/{spec.yaml, plate.step, plate.dxf, drawing_meta.json}
    Single source of truth per plate. cad/ top level now contains only
    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
    [plate.dxf, plate.step]
2026-05-08 ✨ feat: EX-G + EX-C plates (step 6.3)
    Per Q16 step 6.3: external services plates for grid + compute containers,
    mounted on long walls (vs CG/BG-AC on end walls).
    EX-G (grid container long wall, -Y):
    - station service LV conduit (~28mm)
    - SCADA fiber/copper drop (~35mm)
    - M12 ground stud (high fault current path, mirrors BG-AC)
    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
    [plate.dxf, plate.step]
2026-05-08 ♻️ refactor: collapse per-plate wrappers + 4-plate fleet realignment
    Two changes:
    1. Collapse cad/model/{cg,bg_ac,ex_g,ex_c}.py + cad/drawing/{...}.py
    wrappers into single cad/model/build.py + cad/drawing/build.py
    dispatchers. v1 build params now live in each spec.yaml's
    `default_params:` block (single source of truth; spec was already
    the design contract). ~280 LOC of boilerplate removed.
    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
    [plate.dxf, plate.step]
2026-05-09 ✨ feat: defense plate artifacts (step 6.9, plate side)
    cad/model/build.py + cad/drawing/build.py emit per-deployment-context
    artifacts. Defense (5083-H116 marine grade, 10mm, M12 fasteners,
    EPDM secondary seal, Type III hard anodize) goes to:
    cad/specs/{plate_id}/plate-defense.step
    cad/specs/{plate_id}/plate-defense.dxf
    cad/specs/{plate_id}/drawing_meta-defense.json
    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
    [plate-defense.dxf, plate-defense.step, plate.step]
2026-05-09 ✨ feat: corner bolt-hole slots for thermal accommodation (ADR-015)
    Adopted Option 1 from the CG thermal-margin analysis: 4 corner bolt
    holes are radially slotted (13mm slot, 11mm Ø, oriented toward bolt-
    pattern center). Edge-midpoint holes stay round.
    Slot length derivation (theory.ipynb cell 45b88839):
    L_slot = D_hole + 2·(δ_thermal + δ_fab + δ_margin)
    = 11 + 2·(0.449 + 0.1 + 0.2) = 12.5mm → rounded up to 13mm
    That gives 1.0mm radial extra per side vs 0.75mm budget (commercial)
    and 0.89mm budget (defense ΔT=111K MIL-STD-810H), so design carries
    through to defense without rework.
    Changes:
    - _plate.py: MountingBolts.corner_slot_length_mm added (None for
    legacy roun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
    [plate-defense.dxf, plate-defense.step, plate.dxf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]
2026-05-09 📝 docs: theory.ipynb references ADR-017 for non-computed load cases
    Replaces the ADR-XXX placeholder in theory.ipynb opening cell with a
    concrete pointer to ADR-017 in edp-module-assemblies/system_adrs.md
    (deflection, stress concentration, wind — all bounded by inspection).
2026-05-09 Revert "📝 docs: theory.ipynb references ADR-017 for non-computed load cases"
    This reverts commit f863486381030c27a85c50933e3c90e3794bb29c.
2026-05-09 ✨ feat: slot long-axis midpoints + load cases bounded by computation
    Two corrections + one addition:
    1. ADR-015 update: slot the 4 corners AND 2 long-axis midpoints (6 of 8
    bolts), not just corners. Prior wording claimed midpoint offset was "a
    small fraction" of corner offset — actually 81% (long-axis midpoints
    sit 360 mm from pattern center vs 444 mm for corners). Long-axis
    midpoint margin after ISO 2768-m fab tol was only 36 µm — positive
    but too tight to ship. 13 mm slot covers both (budget set by worst
    case, 0.449 mm corner offset). Short-axis midpoints stay round (0.263
    mm offset, ample clearance).
    2. theory.ipynb gains 3 computed load cases ("bounded by co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
    [plate-defense.dxf, plate-defense.step, plate.dxf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]
2026-05-09 📝 docs: assign Joe Narvaez, EIT as plate spec reviewer (#20)
    All 4 plate spec.yamls (CG, BG-AC, BG-DC, CD) had `reviewed_by:
    TBD_pending_human_review`. Updated to:
    reviewed_by: Joe Narvaez, EIT
    reviewed_date: 2026-05-09
2026-05-09 📝 docs: BG-DC is a single parametric variant (#17), not 2/4/8 sub-variants
    Per PM 2026-05-09: BG-DC stays a single variant. DC bus OD is sized
    parametrically on aggregate string current via ADR-011's sizing engine
    (Module F when wired). Sub-variants BG-DC-2 / BG-DC-4 / BG-DC-8 — which
    the readme had previously listed by BESS string count — are not v1 work.
    Updates the variant table, the example BOM JSON, and the part-numbering
    section in readme.md to reflect the single-variant approach.
2026-05-09 ✨ feat: add DELTA_T_DEFENSE = 111 K constant to all 4 plate sims (#19, step 1/4)
    Defense forward operating range per MIL-STD-810H typical: -40 to +71 °C
    (111 K span, vs commercial 85 K span / -25 to +60 °C).
    Step 1: constant only. No callers yet — solve() still hardcodes
    DELTA_T_OPERATING. Behavior unchanged; 22 sim tests still pass.
    Next steps:
    2/4 — parametrize solve(delta_t=DELTA_T_OPERATING) in 4 model.py files
    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
2026-05-09 🐛 fix: bolt-based slot framing in theory.ipynb (consistent with test)
    The slot-derivation cell (45b88839) used hole-based math (slot extra
    beyond Ø11 hole = 1.0mm, defense headroom 0.11mm). The defense
    verdicts cell + the sim test use bolt-based math (slot per-side from
    bolt center = 1.5mm, defense headroom 0.61mm).
    Bolt-based is the directly-physical question: "can the bolt move within
    the slot when the plate thermally expands?" Bolt-to-slot-end clearance
    is the constraint. Hole-based was a derivation shortcut that conflates
    the round-hole's pre-existing 0.5mm clearance with the displacement
    budget.
    Updated slot-derivation cell to:
    - Use min_slot_mm = D_bolt + 2·(thermal + fab + marg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
2026-05-09 🐛 fix: cadquery .center() relative-accumulation bug + remove engraving
    Root cause: .center(x, y) is RELATIVE in cadquery — calling it in a chain
    accumulates offsets. Penetrations and bolts were placed at wrong positions:
    - power_conduit: (0, 300) ✓ — only one correct (first iteration)
    - data_conduit: drilled inside power_conduit (overlap → vanished)
    - ground_stud: at (-200, 0) instead of (-200, -300)
    - bolts/slots: similarly accumulated offsets
    Fix: use .pushPoints([(x, y), ...]) for absolute positioning. Slots also
    fixed via .moveTo(x, y) per iteration (slot2D needs workplane origin).
    Verified positions now correct:
    power: (0, 300), data: (0, 0), ground: (-200, -300)
    corner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
    [CG.dxf, plate-defense.step, plate.dxf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]
2026-05-10 ✨ feat: GD&T fab drawings — plate fleet × per-context
    Generates A1 fab drawings for the 4-plate fleet (CG, BG-AC, BG-DC, CD)
    across commercial + defense_forward deployment contexts. Each drawing
    carries 4 views (TOP + FRONT + ISO + DETAIL 2:1 slot), Ø dims with
    ISO 286-2 H9/H10 tolerances, ground-stud tap callout per context,
    ordinate position block from datums B/C, slot detail with TYP-6-PLACES
    annotation, plate thickness on FRONT, notes block (5 commercial / 6
    defense), and per-context title block (material/finish/PN-D suffix).
    [BG-AC-defense.dxf, BG-DC-defense.dxf, BG-DC.dxf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]
2026-05-10 🚀 ci: publish plate artifacts to s3://arcnode-artifacts/plates
    Adds a deploy stage on main pushes that uploads each plate's
    spec.yaml + plate{,-defense}.step + plate{,-defense}.dxf +
    drawing_meta{,-defense}.json under plates/{plate_id}/v1/.
    edp-module-assemblies' plate_loader.fetch downloads from this prefix;
    without publish here, its CI test_defense_routes_to_evapco_dc_and_dod_bess
    fails on a 404 HeadObject for plates/CG/v1/plate-defense.step.
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
